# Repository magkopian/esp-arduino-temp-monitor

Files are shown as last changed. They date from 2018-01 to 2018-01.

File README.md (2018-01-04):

Temperature and Humidity Monitor
================================

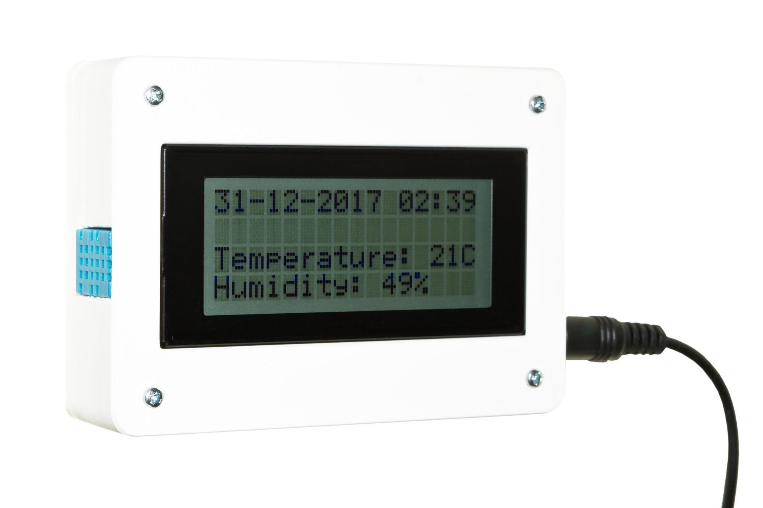
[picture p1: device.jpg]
Device


## Description:

These are the PCB design files and source code for my ESP8266 based temperature and humidity monitor.

The [board](/board) directory contains the KiCAD schematic and PCB layout files together with the [gerber files](/board/gerbers). While the [firmware](/firmware) directory, contains the Arduino source code for the ESP8266. The [server](/server) directory contains the server side script that logs the received data, as well as an SQL file for creating the database tables. Finally, the design files for the enclosure can be found on [Thingiverse](https://www.thingiverse.com/thing:2740731).

For more information and detailed instructions on making your own, checkout my project on [Instructables](https://www.instructables.com/id/Temperature-and-Humidity-Monitor/).

## Programming Instructions:

The firmware can be compiled and burned to an ESP8266 microcontroller using the [Arduino IDE](https://www.arduino.cc/en/Main/Software). To compile the project code you'll also need to install the [SimpleDHT](https://github.com/winlinvip/SimpleDHT/) library package using the [Library Manager](https://www.arduino.cc/en/Guide/Libraries#toc2) of the Arduino IDE. Additionally, for programming the ESP8266 using the Arduino IDE, the [ESP8266 Community](https://github.com/esp8266/Arduino) core package needs to be installed using the [Board Manager](https://www.arduino.cc/en/Guide/Cores).

## License:

The design files for the PCB and the enclosure are all distributed under the [Attribution-ShareAlike 4.0 International](https://creativecommons.org/licenses/by-sa/4.0/) license. The source code for the firmware and the server are distributed under the MIT license.

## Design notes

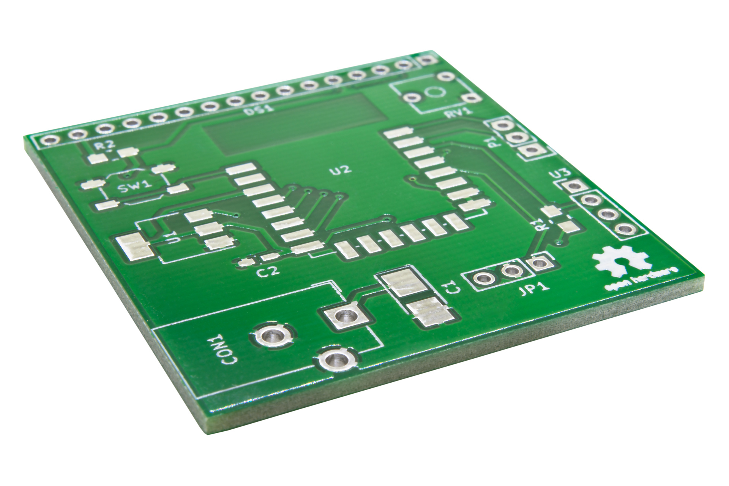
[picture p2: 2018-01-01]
board/bare_pcb_top.jpg

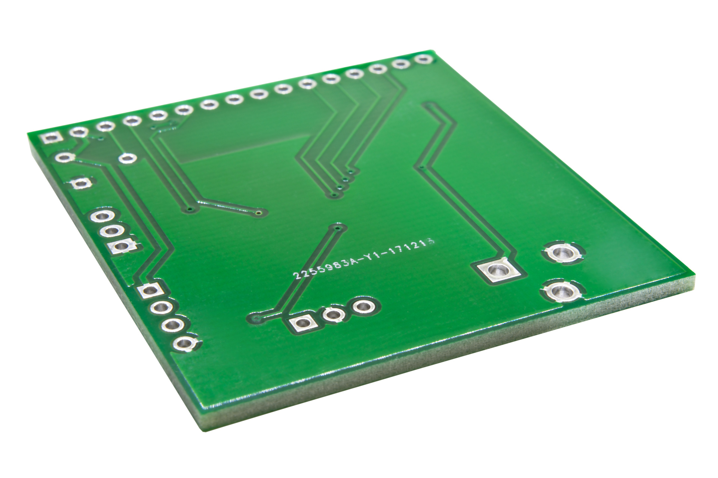
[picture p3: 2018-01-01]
board/bare_pcb_bottom.jpg

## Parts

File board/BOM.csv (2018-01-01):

Id | Designator | Package | Quantity | Designation | Supplier and ref
1 | U2 | ESP-12E_SMD | 1 | ESP-12E
2 | C1 | CP_Tantalum_Case-B_EIA-3528-21_Hand | 1 | 10uF
3 | C2 | C_0603_HandSoldering | 1 | 100nF
4 | CON1 | Barrel_Jack_CUI_PJ-102AH | 1 | POWER_IN
5 | DS1 | Pin_Header_Straight_1x16_Pitch2.54mm | 1 | LCD-016N002L
6 | P1 | Pin_Header_Straight_1x03 | 1 | PROGRAMMING_HEADER
7 | R1 | R_0805_HandSoldering | 1 | 10K
8 | R2 | R_0805_HandSoldering | 1 | 47R
9 | RV1 | Potentiometer_Trimmer_ACP_CA6v_Horizontal | 1 | 10K
10 | U1 | SOT-223-3_TabPin2 | 1 | LD1117S33TR
11 | SW1 | SW_SPST_TL3342 | 1 | RESET
12 | JP1 | Pin_Header_Straight_1x03_Pitch2.54mm | 1 | Jumper
13 | U3 | Pin_Header_Straight_1x04_Pitch2.54mm | 1 | DHT11

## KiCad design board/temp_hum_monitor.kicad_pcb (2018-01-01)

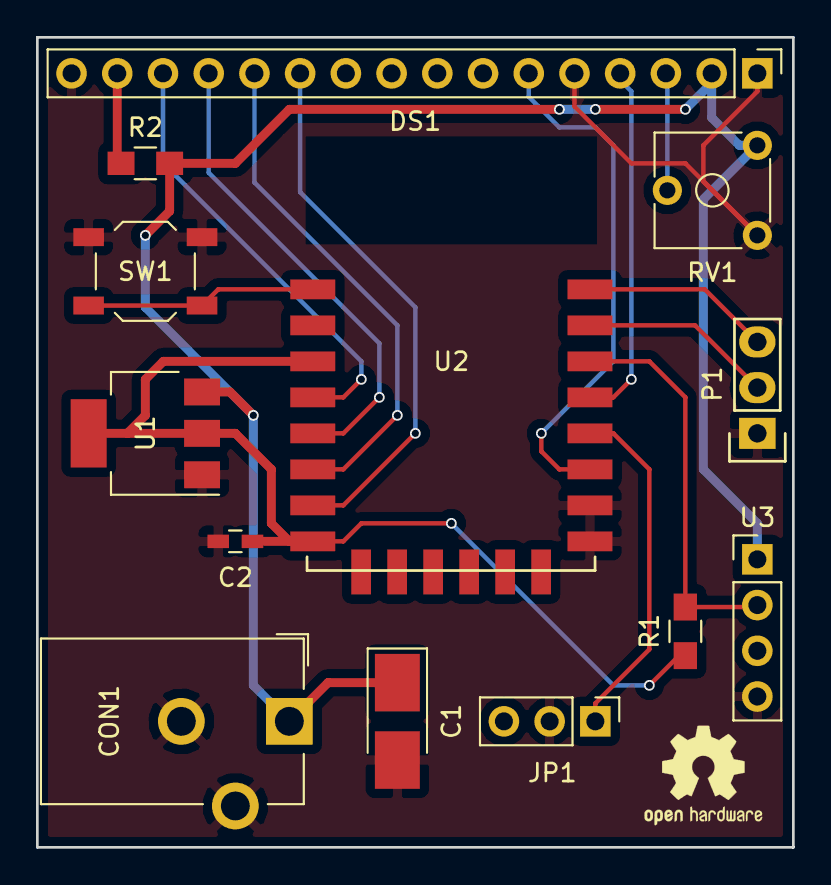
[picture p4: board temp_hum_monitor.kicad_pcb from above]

Board: 2 copper layers, 42.0 x 45.0 mm, 13 parts (0 on the bottom side), 16 nets.

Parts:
C1: 10uF; CP_Tantalum_Case-B_EIA-3528-21_Hand
C2: 100nF; C_0603_HandSoldering
CON1: POWER_IN; Barrel_Jack_CUI_PJ-102AH
DS1: LCD-016N002L; Pin_Header_Straight_1x16_Pitch2.54mm
JP1: Jumper; Pin_Header_Straight_1x03_Pitch2.54mm
P1: PROGRAMMING_HEADER; Pin_Header_Straight_1x03
R1: 10K; R_0805_HandSoldering
R2: 47R; R_0805_HandSoldering
RV1: 10K; Potentiometer_Trimmer_ACP_CA6v_Horizontal
SW1: RESET; SW_SPST_TL3342
U1: LD1117S33TR; SOT-223-3_TabPin2
U2: ESP-12E; ESP-12E_SMD
U3: DHT11; Pin_Header_Straight_1x04_Pitch2.54mm

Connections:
+3V3: C2.1, R1.1, U1.2, U2.3, U2.8
+5V: C1.1, CON1.1, DS1.2, R2.2, RV1.1, U1.3, U3.1
/ESP_RX: P1.2, U2.15
/ESP_TX: P1.3, U2.16
/LCD_D4: DS1.11, U2.7
/LCD_D5: DS1.12, U2.6
/LCD_D6: DS1.13, U2.5
/LCD_D7: DS1.14, U2.4
/LCD_E: DS1.6, U2.11
/LCD_RS: DS1.4, U2.13
GND: C1.2, C2.2, CON1.2, CON1.3, DS1.1, DS1.5, DS1.16, JP1.2, P1.1, RV1.3, SW1.2, U1.1, U2.9, U2.10, U3.4
unnamed: DS1.3, RV1.2
unnamed: DS1.15, R2.1
unnamed: JP1.1, U2.12
unnamed: R1.2, U2.14, U3.2
unnamed: SW1.1, U2.1

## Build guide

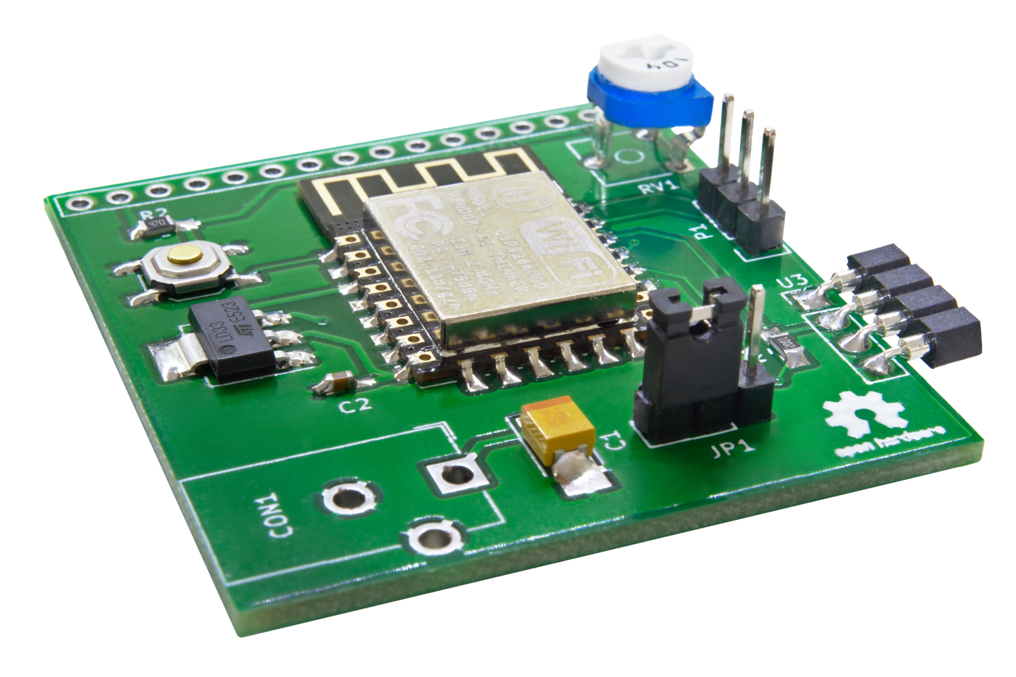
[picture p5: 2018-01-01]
board/soldered_pcb.jpg

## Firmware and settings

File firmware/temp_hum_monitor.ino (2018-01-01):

/*
* Copyright (c) 2017 Manolis Agkopian
* See the file LICENSE for copying permission.
*/

#include <Arduino.h>

#include <ESP8266WiFi.h>
#include <ESP8266WiFiMulti.h>
#include <ESP8266HTTPClient.h>

#include <LiquidCrystal.h>
#include <SimpleDHT.h>

ESP8266WiFiMulti WiFiMulti;

const int rs = 4, en = 2, d4 = 13, d5 = 12, d6 = 14, d7 = 16;
LiquidCrystal lcd(rs, en, d4, d5, d6, d7);

int DHT11 = 5;
SimpleDHT11 dht;

void setup() {

  // Configure LCD
  lcd.begin(16, 4);

  // Configure WiFi
  WiFiMulti.addAP("[SSID]", "[Password]");

}

void loop() {
  
  byte temperature = 0;
  byte humidity = 0;
  char postData[100] = {0};

  // Sample rate is set to 1 Hz
  delay(1000);

  // Read the sensor
  if ( dht.read(DHT11, &temperature, &humidity, NULL) != SimpleDHTErrSuccess ) {
    lcd.setCursor(0, 1);
    lcd.print("Sensor Failure"); // In case of error output sensor failure and return
    return;
  }

  // Clear the sensor failure error message
  lcd.setCursor(0, 1);
  lcd.print("              ");

  // Output the temperature
  lcd.setCursor(0, 2);
  lcd.print("Temperature: ");
  lcd.print((int) temperature);
  lcd.print("C");

  // Output the humidity
  lcd.setCursor(0, 3);
  lcd.print("Humidity: ");
  lcd.print((int) humidity);
  lcd.print("%");

  sprintf(postData, "{\"client_id\":\"[Client ID]\",\"client_key\":\"[Client Key]\",\"temperature\":\"%d\",\"humidity\":\"%d\"}", (int) temperature, (int) humidity);
  
  // If connected to the WiFi send the mesurment to the server
  if((WiFiMulti.run() == WL_CONNECTED)) {
    
    HTTPClient http;

    // Set request URL
    http.begin("http://[Host]/log.php"); // For HTTPS connection the fingerprint of the certificate needs to be supplied as a second parameter

    // Start connection and send HTTP headers
    http.addHeader("Content-Type", "application/json");
    http.addHeader("Accept", "application/json");
    int httpCode = http.POST(postData);

    if( httpCode > 0 && httpCode == HTTP_CODE_OK ) {
      String payload = http.getString();
      lcd.setCursor(0, 0);
      lcd.print(payload);
    }
    else {
      String error = http.errorToString(httpCode).c_str();
    }

    http.end();
    
  }
  
}

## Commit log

2018-01-01 Added PCB design and gerber files
    [BOM.csv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]
2018-01-01 Added firmware source code
    [BOM.csv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]
2018-01-01 Added README and LICENSE files
    [BOM.csv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]
